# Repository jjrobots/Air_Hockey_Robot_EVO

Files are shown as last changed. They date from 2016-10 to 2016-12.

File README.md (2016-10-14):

AIR HOCKEY ROBOT EVO
====================
This is the EVOlution of the original Air Hockey Robot project!
This is version is more easy to build, user friendly, cheap and fun!

This project is an Air hockey Robot cotrolled by Arduino with a vision system to detect the puck position.
This project uses the same JJROBOTS brain shield and motors than BROBOT project and iBoardBot project

Documentation, features, how it works, build manuals and SHOP here:
URL: http://jjrobots.com/air-hockey-robot-EVO

This is the new and improved version of this old project:
URL: https://www.youtube.com/watch?v=CjzSeOg8oTs

JJROBOTS 2016. Science & fun!

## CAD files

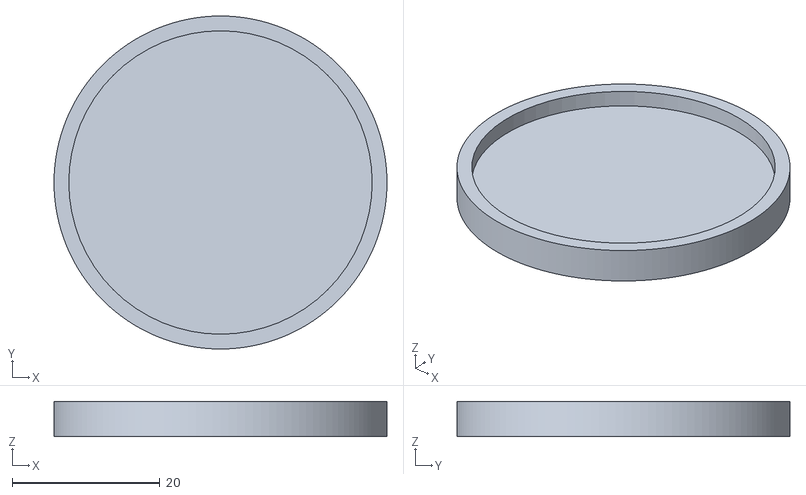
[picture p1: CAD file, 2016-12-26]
3DParts/puck.stl
45.0 x 45.0 x 4.75

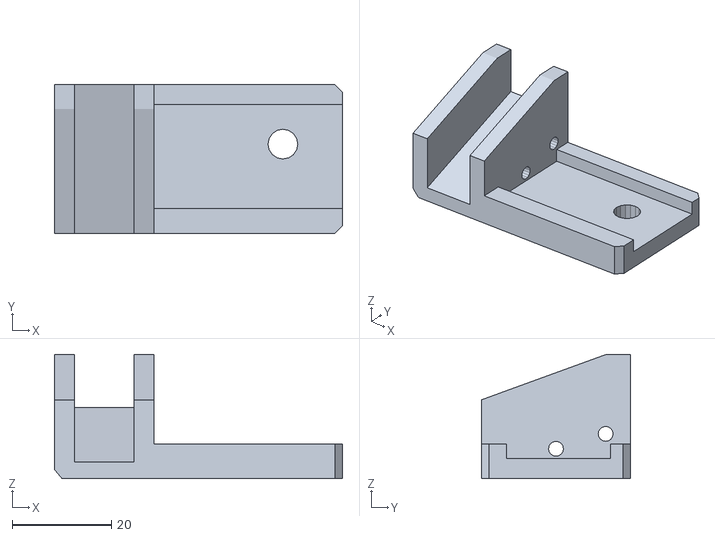
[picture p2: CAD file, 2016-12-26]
3DParts/smartphone_support.stl
58.0 x 30.0 x 25.0

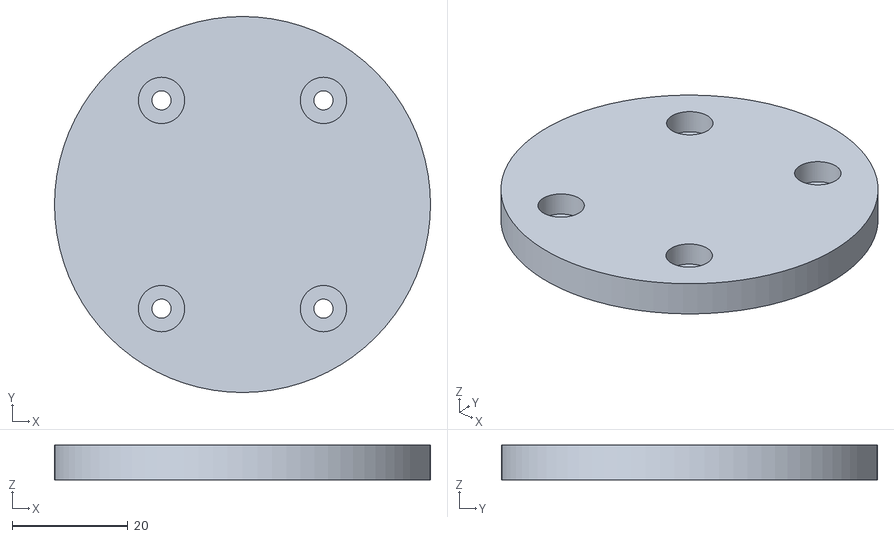
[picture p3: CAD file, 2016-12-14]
3DParts/pusher_robot2.stl
65.0 x 65.0 x 6.00

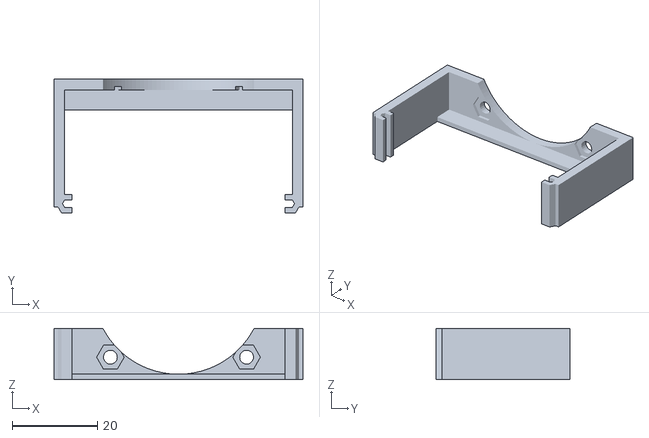
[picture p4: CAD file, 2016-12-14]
3DParts/FAN SUPPORT.stl
58.5 x 31.4 x 12.0

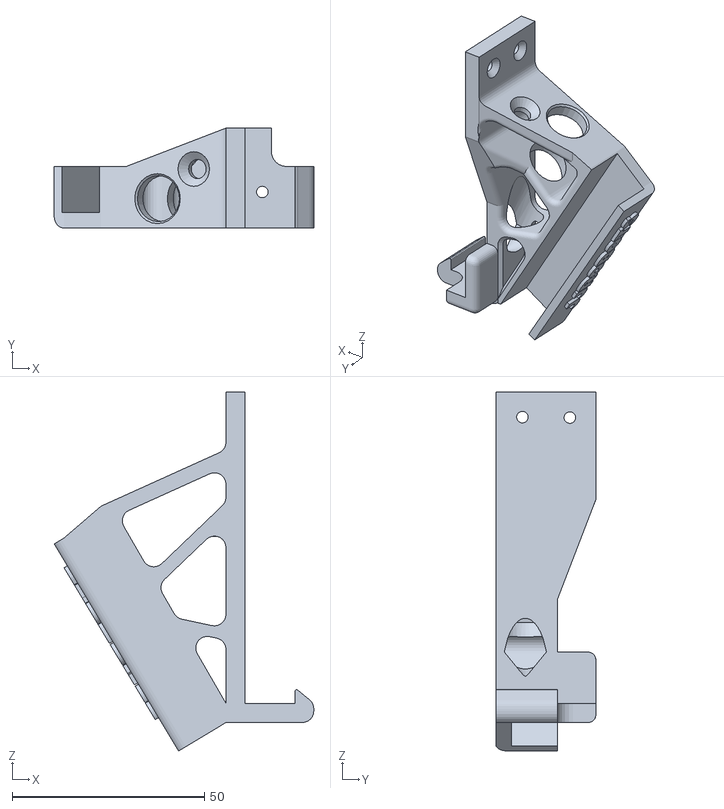
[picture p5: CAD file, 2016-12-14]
3DParts/Pole support.stl
67.6 x 26.0 x 93.4

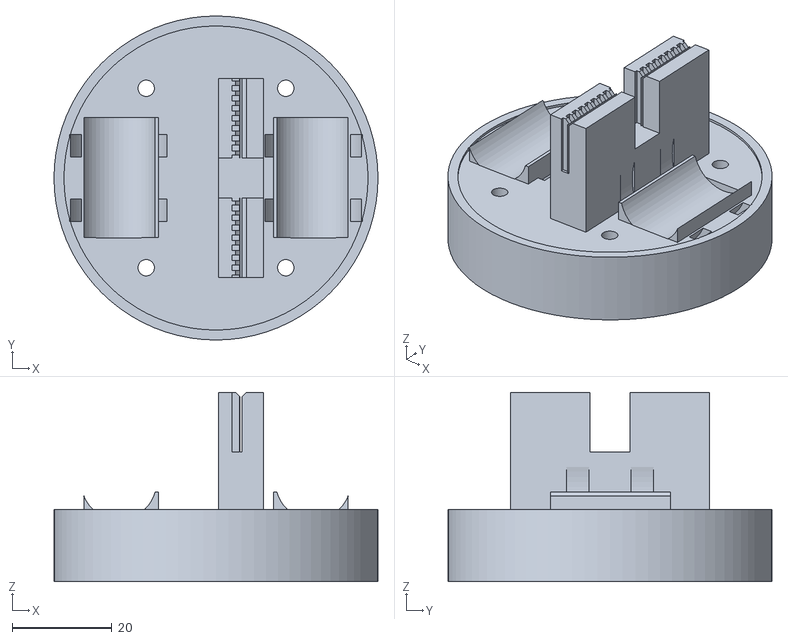
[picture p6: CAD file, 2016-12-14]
3DParts/pusher_robot.stl
65.0 x 65.0 x 38.0

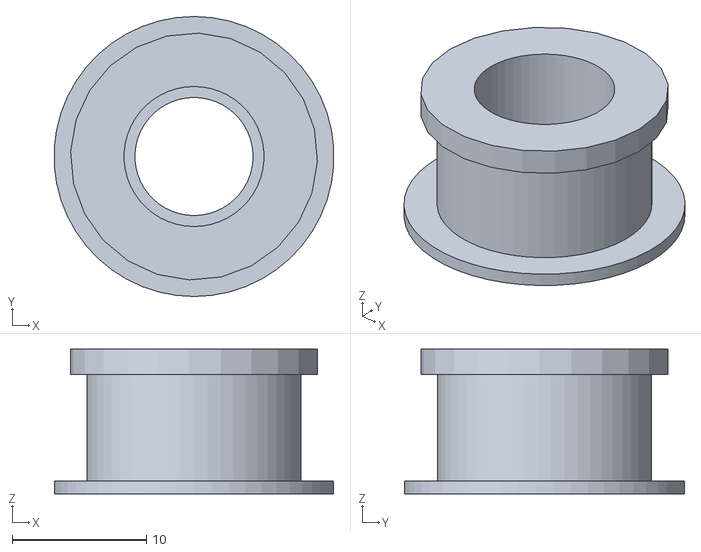
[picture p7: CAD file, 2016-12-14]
3DParts/pulley 2x623.stl
20.8 x 20.8 x 10.8

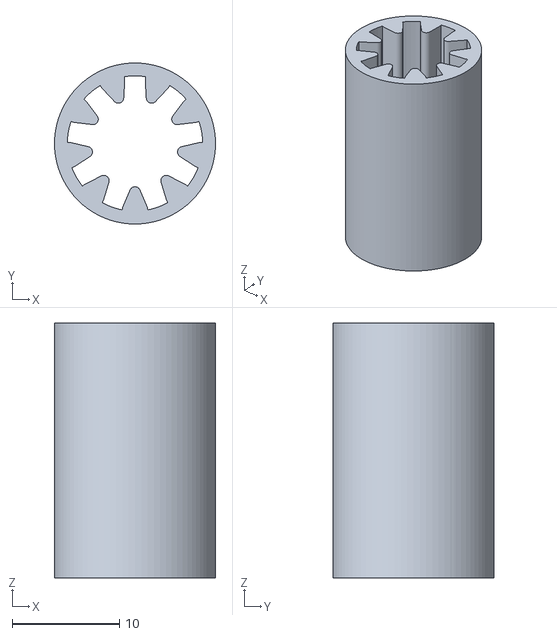
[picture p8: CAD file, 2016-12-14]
3DParts/PrintableBushing.stl
15.0 x 15.0 x 23.8

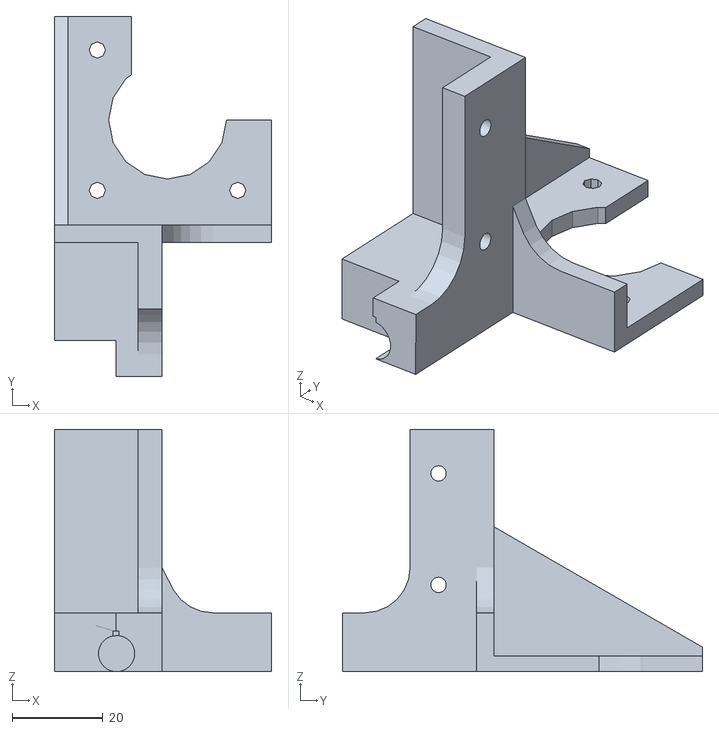
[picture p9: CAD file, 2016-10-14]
3DParts/MOTOR SUPPORT RIGHT.stl
48.0 x 79.5 x 53.5

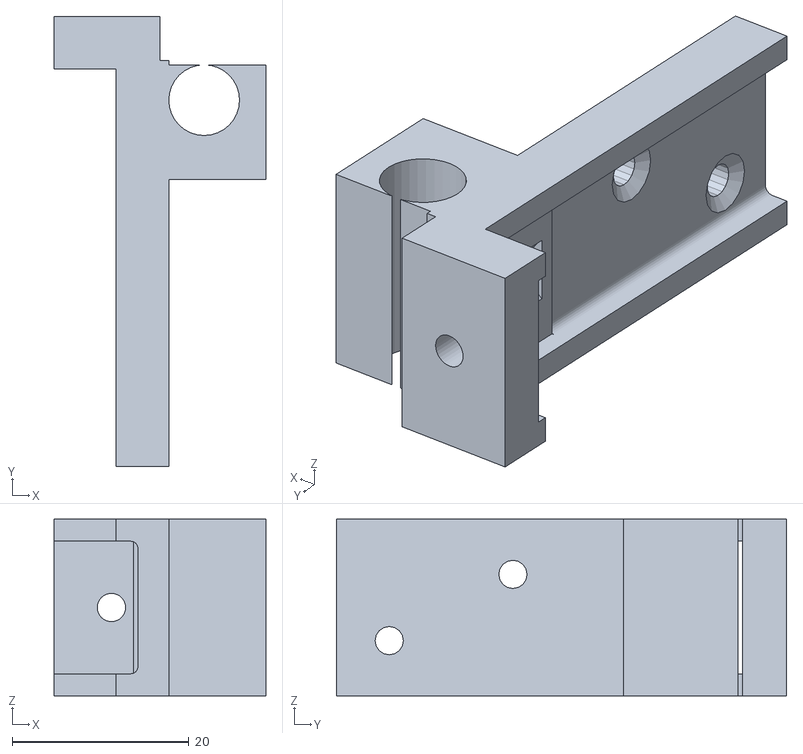
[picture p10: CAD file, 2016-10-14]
3DParts/LATERAL SUPPORT.stl
24.0 x 51.0 x 20.0

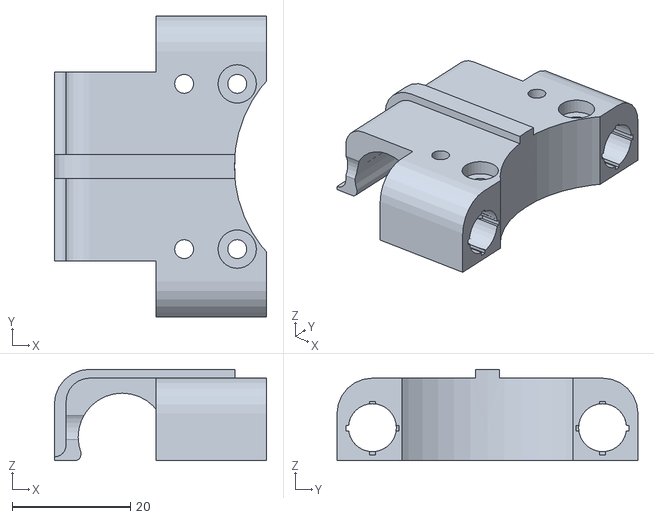
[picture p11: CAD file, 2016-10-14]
3DParts/LATERAL SLIDER.stl
36.0 x 51.0 x 15.5

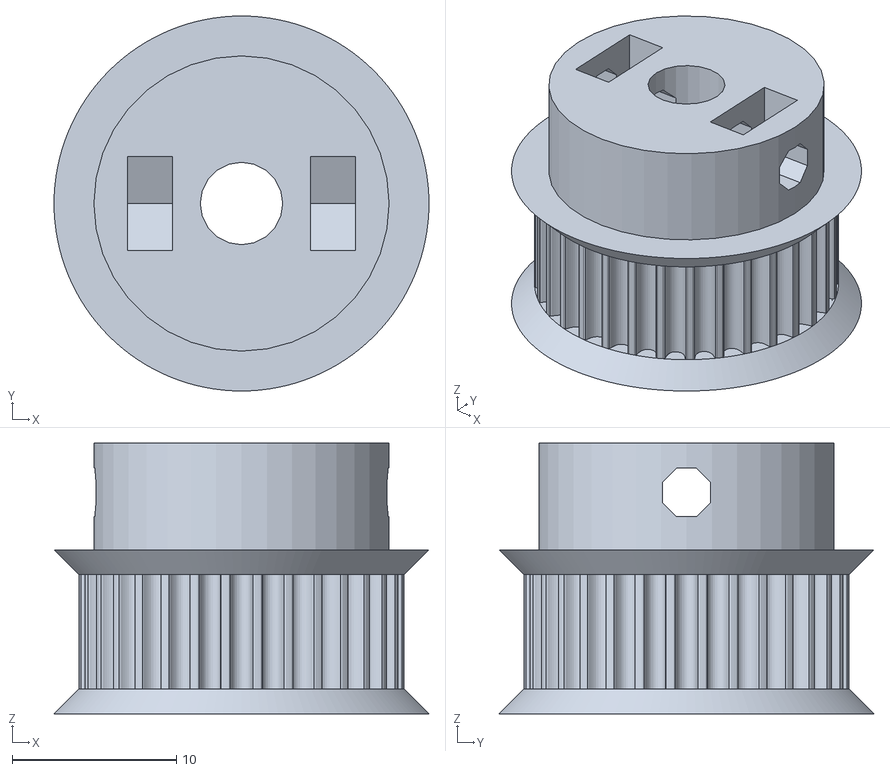
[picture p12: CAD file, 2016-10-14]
3DParts/MOTOR PULLEY.stl
22.9 x 22.9 x 16.5

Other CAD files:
3DParts/MOTOR SUPPORT LEFT.stl

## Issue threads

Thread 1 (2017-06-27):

Robot not working properly

LuisDiazUgena, 2017-06-27:
Hi!

I need to make the air hockey robot to work properly and seems that the motors are running in incorrect directions. Using the manual mode moves forward and backwards properly, but the left and right directions seems to be inverted (when need to move left it moves right and viceversa).

I have connected, from robot side, the left motor to motor1 port and the right motor to motor2 port, as said in the build instructions.

I've tested with the firmware that came preloaded and upgraded with the last code in github and I've the same problem.

Thanks!

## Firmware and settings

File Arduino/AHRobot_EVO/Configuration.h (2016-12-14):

// JJROBOTS AHR AIR HOCKEY ROBOT EVO PROJECT

// USER CONFIGURATIONS HERE
// ROBOT DIMENSIONS, MAX SPEED, MAX ACCELERATION, CALIBRATION...

//#define DEBUG

// ABSOLUTE MAX ROBOT SPEED AND ACCELERATION
// THIS VALUES DEPENDS ON YOUR ROBOT CONSTRUCTION (MOTORS, MECHANICS...)
// RECOMMENDED VALUES FOR 12V POWER SUPPLY
#define MAX_ACCEL 275           // Maximun motor acceleration in (steps/seg2)/1000. Max recommended value:280
#define MAX_SPEED 32000         // Maximun speed in steps/seg. Max absolute value: 32767!!

#define MIN_ACCEL 100
#define MIN_SPEED 5000
#define SCURVE_LOW_SPEED 2500
#define SCURVE_HIGH_SPEED 28000

// Geometric calibration.
// This depends on the pulley teeth. DEFAULT: 200(steps/rev)*8(microstepping) = 1600 steps/rev. 1600/32teeth*2mm(GT2) = 25 steps/mm
#define X_AXIS_STEPS_PER_UNIT 25    
#define Y_AXIS_STEPS_PER_UNIT 25

// This is the center of the table. All units in milimeters
// This are the dimensions of the official air hockey table Exploter from Buffalo
#define TABLE_LENGTH 895
#define TABLE_WIDTH 435
#define ROBOT_CENTER_X TABLE_WIDTH/2   // Center of robot.
#define ROBOT_CENTER_Y TABLE_LENGTH/2

// Absolute Min and Max robot positions in mm (measured from center of robot pusher)
#define ROBOT_MIN_X 60
#define ROBOT_MIN_Y 58
#define ROBOT_MAX_X TABLE_WIDTH-ROBOT_MIN_X
#define ROBOT_MAX_Y ROBOT_CENTER_Y-80

// PuckSize (puck radio in mm)
#define PUCK_SIZE 22

// Initial robot position in mm
// The robot must be at this position at start time
// Default: Centered in X and minimun position in Y
#define ROBOT_INITIAL_POSITION_X TABLE_WIDTH/2
#define ROBOT_INITIAL_POSITION_Y 40   // Measured from center of the robot pusher to the table border

// Robot defense and attack lines
#define ROBOT_DEFENSE_POSITION_DEFAULT 72
#define ROBOT_DEFENSE_ATTACK_POSITION_DEFAULT 280
#define ROBOT_DEFENSE_POSITION_MIN 60
#define ROBOT_DEFENSE_POSITION_MAX 100
#define ROBOT_DEFENSE_ATTACK_POSITION_MIN 140
#define ROBOT_DEFENSE_ATTACK_POSITION_MAX 360

// CORRECTION FOR VISION SYSTEM LAG
#define VISION_SYSTEM_LAG 60   // in miliseconds

// CORRECTION OF MISSING STEPS ON MOTORS
// Coment this lines if you don´t want to make the corrections
#define CORRECT_MISSING_STEPS 1
#define MISSING_STEPS_MAX_ERROR_X 5
#define MISSING_STEPS_MAX_ERROR_Y 5
#define ROBOT_POSITION_CAMERA_CORRECTION_Y 0 // Correction of the position of the camera because the camera point of view and mark position

// PACKET SIZE (UDP MESSAGE)
#define PACKET_SIZE 12  // UDP PACKET SIZE (without sync mark), total size = PACKET_SIZE+3(sync mark)

// Utils (don´t modify)
#define CLR(x,y) (x&=(~(1<<y)))
#define SET(x,y) (x|=(1<<y))

#define RAD2GRAD 57.2957795
#define GRAD2RAD 0.01745329251994329576923690768489

#define ZERO_SPEED 65535

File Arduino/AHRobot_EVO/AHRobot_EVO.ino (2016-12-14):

// JJROBOTS AHR: AIR HOCKEY ROBOT EVO PROJECT (Smartphone control ready!)
// Author: Jose Julio (JJROBOTS)
// Hardware: Arduino Leonardo + JJROBOTS brain shield v3 (devia)
// Date: 04/11/2015
// Last updated: 14/12/2016
// Version: 2.17
// Project page :
//   http://jjrobotos.com/air-hockey-robot-evo/
// GIT repository:
//   http://github.com/jjrobots/Air_Hockey_Robot_EVO/
// License: Open Software GPL License

#define VERSION "2.17"

// ROBOT and USER configuration parameters
#include "Configuration.h"
#include "Definitions.h"   // Variable definitions

void setup()
{
  // STEPPER PINS ON JJROBOTS BRAIN SHIELD
  pinMode(4, OUTPUT); // ENABLE MOTORS
  pinMode(7, OUTPUT); // STEP MOTOR 1 PORTE,6
  pinMode(8, OUTPUT); // DIR MOTOR 1  PORTB,4
  pinMode(12, OUTPUT); // STEP MOTOR 2 PORTD,6
  pinMode(5, OUTPUT); // DIR MOTOR 2  PORTC,6
  digitalWrite(4, HIGH);  // Disbale stepper motors

  pinMode(10, OUTPUT);  // Servo1 (arm)
  pinMode(13, OUTPUT);  // Servo2

  pinMode(A4, OUTPUT);  // Microstepping selector
  digitalWrite(A4, LOW); // 1/8 Microstepping

  pinMode(A3,INPUT);   // User puch button (pushed=>gnd)
  digitalWrite(A3,HIGH); // Enable pullup

  Serial.begin(115200);   // PC debug connection
  Serial1.begin(115200);  // ESP serial connection
  delay(5000);
  Serial.print("AHR JJRobots Air Hockey Robot EVO version ");
  Serial.println(VERSION);
  delay(1000);

  //LED blink
  for (uint8_t k = 0; k < 5; k++)
  {
    digitalWrite(13, HIGH);
    delay(300);
    digitalWrite(13, LOW);
    delay(300);
  }

  Serial.println("Initializing Wifi module...");
  // ESP Wifi module initialization routine.
  // The Robot will generate it´s own wifi network JJROBOTS_xx and listen external UDP messages...
  ESPInit();

  Serial.println("Initializing Stepper motors...");
  // STEPPER MOTORS INITIALIZATION
  // We use TIMER 1 for stepper motor 1 and Timer 3 for motor 2
  // TIMER1 CTC MODE
  TCCR1B &= ~(1 << WGM13);
  TCCR1B |=  (1 << WGM12);
  TCCR1A &= ~(1 << WGM11);
  TCCR1A &= ~(1 << WGM10);

  // output mode = 00 (disconnected)
  TCCR1A &= ~(3 << COM1A0);
  TCCR1A &= ~(3 << COM1B0);

  // Set the timer pre-scaler
  // Generally we use a divider of 8, resulting in a 2MHz timer on 16MHz CPU
  TCCR1B = (TCCR1B & ~(0x07 << CS10)) | (2 << CS10);

  OCR1A = ZERO_SPEED;   // Motor stopped
  dir_M1 = 0;
  TCNT1 = 0;

  // We use TIMER 3 for stepper motor 2
  // STEPPER MOTORS INITIALIZATION
  // TIMER3 CTC MODE
  TCCR3B &= ~(1 << WGM13);
  TCCR3B |=  (1 << WGM12);
  TCCR3A &= ~(1 << WGM11);
  TCCR3A &= ~(1 << WGM10);

  // output mode = 00 (disconnected)
  TCCR3A &= ~(3 << COM1A0);
  TCCR3A &= ~(3 << COM1B0);

  // Set the timer pre-scaler
  // Generally we use a divider of 8, resulting in a 2MHz timer on 16MHz CPU
  TCCR3B = (TCCR3B & ~(0x07 << CS10)) | (2 << CS10);

  OCR3A = ZERO_SPEED;   // Motor stopped
  dir_M2 = 0;
  TCNT3 = 0;

  delay(1000);
  TIMSK1 |= (1 << OCIE1A); // Enable Timer1 interrupt
  TIMSK3 |= (1 << OCIE1A); // Enable Timer1 interrupt

  // Enable steppers
  digitalWrite(4, LOW);

  delay(1000);

  //Initializing Robot initial position and parameters...
  position_M1 = (ROBOT_INITIAL_POSITION_X + ROBOT_INITIAL_POSITION_Y) * X_AXIS_STEPS_PER_UNIT;
  position_M2 = (ROBOT_INITIAL_POSITION_X - ROBOT_INITIAL_POSITION_Y) * Y_AXIS_STEPS_PER_UNIT;
  target_position_M1 = position_M1;
  target_position_M2 = position_M2;

  user_max_speed = MAX_SPEED;
  user_max_accel = MAX_ACCEL;
  max_acceleration = user_max_accel;
  max_speed = user_max_speed / 2;
  user_robot_defense_position = ROBOT_DEFENSE_POSITION_DEFAULT;
  user_robot_defense_attack_position = ROBOT_DEFENSE_ATTACK_POSITION_DEFAULT;
  defense_position = ROBOT_DEFENSE_POSITION_DEFAULT;   // Robot y axis defense position
  attack_position = ROBOT_DEFENSE_ATTACK_POSITION_DEFAULT;   // Robot y axis position for defense+attack

  // Output parameters to console
  Serial.print("Max_acceleration: ");
  Serial.println(user_max_accel);
  Serial.print("Max speed: ");
  Serial.println(user_max_speed);
  Serial.println("Moving to initial position...");
  Serial.println("Ready!!");

  setPosition_straight(ROBOT_CENTER_X, ROBOT_DEFENSE_POSITION_DEFAULT);

  Serial.print("Target_position:");
  Serial.print(ROBOT_CENTER_X);
  Serial.print(",");
  Serial.println(ROBOT_DEFENSE_POSITION_DEFAULT);
  //Serial.print(";");
  //Serial.print(target_position_M1);
  //Serial.print(",");
  //Serial.println(target_position_M2);

  digitalWrite(13, HIGH);
  Serial.print("AHR JJRobots Air Hockey Robot EVO version ");
  Serial.println(VERSION);
  Serial.println("ready...");

  testmode=false;
  robot_status = 0;
  timer_old = micros();
  timer_packet_old = timer_old;
  micros_old = timer_old;
}

// Main loop
void loop()
{
  int dt;
  uint8_t logOutput = 0;

  debug_counter++;

  if (analogRead(A3)<100) // pushbutton pushed => TEST PATTERN
  {
    loop_counter=0;
    testmode=true;
  }
  
  timer_value = micros();
  if ((timer_value - timer_old) >= 1000) // MAIN 1Khz loop
  {
    timer_old = timer_value;
    loop_counter++;

    packetRead();  // Check for new packets...
    if (newPacket > 0)
    {
      dt = (timer_value - timer_packet_old) / 1000.0;
      //Serial.println(dt);
      //dt = 16;  //60 Hz = 16.66ms
      timer_packet_old = timer_value;
      logOutput = 0;

      Serial.print("P");
      Serial.print(newPacket);

      if (newPacket == 1) // Camera packet
      {
        // Puck detection and trayectory prediction
        cameraProcess(dt);
        // Strategy based on puck prediction
        newDataStrategy();
        // Serial output (DEBUG)
        //Serial.print(" ");
        //Serial.print(cam_timestamp);
        //Serial.print(" ");
        //Serial.print(puckCoordX);
        //Serial.print(",");
        //Serial.print(puckCoordY);
        //Serial.print(" ");
        //Serial.print(predict_status);
        //Serial.print(",");
        //Serial.print(robot_status);
      }
      else if (newPacket == 2) { // User sends a manual move
        robot_status = 5;    // Manual mode
        Serial.print(" ");
        Serial.print(user_target_x);
        Serial.print(",");
        Serial.print(user_target_y);
      }
      else if (newPacket == 3) {
        Serial.print(" USER MAX SPEED:");
        Serial.println(user_max_speed);
        Serial.print("USER MAX ACCEL:");
        Serial.println(user_max_accel);
        Serial.print("USER DEFENSE POSITION:");
        Serial.println(user_robot_defense_position);
        Serial.print("USER ATTACK POSITION:");
        Serial.print(user_robot_defense_attack_position);
      }

      robotStrategy();

      // Robot position detection for missing steps detection in stepper motors.
      missingStepsDetection();

      Serial.println();
      newPacket = 0;
    }  // End packet received

    if (testmode)
      testMovements();

#ifdef DEBUG
    // DEBUG: We inform of the position error of the robot as seen in the camera (util for calibrations)
    if ((loop_counter % 1293) == 0) {
      Serial.print("ROBOT MSD: ");
      Serial.print(robotMissingStepsErrorX);
      Serial.print(",");
      Serial.println(robotMissingStepsErrorY);
    }
#endif

    if ((loop_counter % 10) == 0)
      updatePosition_straight();  // update straight line motion algorithm

    // Position, speed and acceleration control:
    positionControl();
  } // 1Khz loop
}

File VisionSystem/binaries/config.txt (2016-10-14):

# AHR_EVO configuration file 
CAMERA 0         # 0=FIRST CAMERA, 1=SECOND CAMERA, -1=OPEN "input.mpeg" file video
PROTOCOL UDP
CAMPIXTOMM 1.25  # THIS DEPENDS ON YOUR CAMERA POSITION
TABLELENGTH 710  # TABLE SIZE IN mm
TABLEWIDTH 400
PUCKMINH 80      # PUCK HSV DETECTION PARAMETERS
PUCKMAXH 126
PUCKMINS 35
PUCKMAXS 155
PUCKMINV 50
PUCKMAXV 190
ROBOTMINH 136      # ROBOT HSV DETECTION PARAMETERS
ROBOTMAXH 172
ROBOTMINS 126
ROBOTMAXS 217
ROBOTMINV 67
ROBOTMAXV 162
ROBOTYOFFSET 38  # Robot offset from robot mark (projected to table) to robot puck center
FPS 60
VIDEOOUTPUT YES  # YES or NO
LOG YES          # YES or NO
PREVIEW YES      # YES or NO or RAW

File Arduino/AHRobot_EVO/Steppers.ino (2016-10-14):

// JJROBOTS AHR AIR HOCKEY ROBOT EVO PROJECT
// STEPPERS MOTOR CONTROL
// Updated: Now it supports DRV8825 drivers and A4988 drivers
// SPEED, ACCELERATION AND POSITION CONTROL using Arduino 16 bit Timer interrupts
// We control the speed of the motors with interrupts (Timer1 and Timer3). tested up to 32Khz.
// The position of the motor is controlled at 1Khz (in the main loop)

// TIMER 1 : STEPPER MOTOR SPEED CONTROL MOTOR1
ISR(TIMER1_COMPA_vect)
{
  if (dir_M1 == 0)
    return;

  SET(PORTE, 6); // STEP X-AXIS (MOTOR1)
  position_M1 += dir_M1;
  __asm__ __volatile__ (
    "nop" "\n\t"
    "nop" "\n\t"
    "nop" "\n\t"
    "nop" "\n\t"
    "nop" "\n\t"
    "nop" "\n\t"
    "nop" "\n\t"
    "nop" "\n\t"
    "nop" "\n\t"
    "nop" "\n\t"
    "nop" "\n\t"
    "nop");  // Wait for step pulse
  CLR(PORTE, 6);
}

// TIMER 3 : STEPPER MOTOR SPEED CONTROL MOTOR2
ISR(TIMER3_COMPA_vect)
{
  if (dir_M2 == 0)
    return;

  SET(PORTD, 6); // STEP Y-AXIS (Motor2)
  position_M2 += dir_M2;
  __asm__ __volatile__ (
    "nop" "\n\t"
    "nop" "\n\t"
    "nop" "\n\t"
    "nop" "\n\t"
    "nop" "\n\t"
    "nop" "\n\t"
    "nop" "\n\t"
    "nop" "\n\t"
    "nop" "\n\t"
    "nop");  // Wait for step pulse
  CLR(PORTD, 6);
}

// POSITION CONTROL
// We use a ramp for acceleration and deceleration
// To calculate the point we should start to decelerate we use this formula:
// stop_position = actual_posicion + (actual_speed*actual_speed)/(2*max_deceleration)
// Input parameters:
//    target_position_M1
//    target_speed_M1
//    max_acceleration

void positionControl()
{
  int32_t temp;
  uint32_t timer;
  int16_t dt;
  int16_t result_speed_M1, result_speed_M2;
  int16_t absSpeedM1, absSpeedM2;


  real_position_x = ((position_M1 + position_M2) / 2) / X_AXIS_STEPS_PER_UNIT;
  real_position_y = ((position_M1 - position_M2) / 2) / Y_AXIS_STEPS_PER_UNIT;
  //SET(PORTF,3); // for external timing debug
  timer = micros();
  // dt = delta time in microseconds...
  dt = constrain(timer - micros_old, 0, 2000); // Limit dt (it should be around 1000 most times, 1ms)
  //Serial.println(dt);
  micros_old = timer;

  // Movement accelerations...
  acceleration_M1 = max_acceleration;
  acceleration_M2 = max_acceleration;

  // Scurve profile implementation...
  absSpeedM1 = abs(speed_M1);
  absSpeedM2 = abs(speed_M2);
  if (absSpeedM1 < SCURVE_LOW_SPEED) {
    acceleration_M1 = map(absSpeedM1, 0, SCURVE_LOW_SPEED, MIN_ACCEL, max_acceleration);
    if (acceleration_M1 > max_acceleration)
      acceleration_M1 = max_acceleration;
  }
  if (absSpeedM2 < SCURVE_LOW_SPEED) {
    acceleration_M2 = map(absSpeedM2, 0, SCURVE_LOW_SPEED, MIN_ACCEL, max_acceleration);
    if (acceleration_M2 > max_acceleration)
      acceleration_M2 = max_acceleration;
  }
  // SCURVE FACOR 1900!!!

  // MOTOR1 M1
  temp = (long)speed_M1 * speed_M1;
  temp = temp / (1900 * (long)acceleration_M1);
  pos_stop_M1 = position_M1 + sign(speed_M1) * temp;    // We calculate the stop position if we apply a deceleration right now.
  if (target_position_M1 > position_M1)    // Positive move
  {
    if (pos_stop_M1 >= target_position_M1)  // Do we need to start stopping?
      result_speed_M1 = 0;                    // The deceleration ramp is done inside the setSpeed function
    else
      result_speed_M1 = target_speed_M1;      // The aceleration ramp is done inside the setSpeed function
  }
  else   // Negative move
  {
    if (pos_stop_M1 <= target_position_M1)  // Start decelerating?
      result_speed_M1 = 0;
    else
      result_speed_M1 = -target_speed_M1;
  }

  // MOTOR2 M2
  temp = (long)speed_M2 * speed_M2;
  temp = temp / (1900 * (long)acceleration_M2);
  pos_stop_M2 = position_M2 + sign(speed_M2) * temp;
  if (target_position_M2 > position_M2) // Positive move
  {
    if (pos_stop_M2 >= target_position_M2)  // Start decelerating?
      result_speed_M2 = 0;                  // The deceleration ramp is done inside the setSpeed function
    else
      result_speed_M2 = target_speed_M2;    // The aceleration ramp is done inside the setSpeed function
  }
  else   // Negative move
  {
    if (pos_stop_M2 <= target_position_M2)  // Start decelerating?
      result_speed_M2 = 0;
    else
      result_speed_M2 = -target_speed_M2;
  }

  setMotorSpeed(result_speed_M1, result_speed_M2, dt); // change Motors speed
  //CLR(PORTF,3); // for external timing debug
}

// Speed could be positive or negative
void setMotorSpeed(int16_t m1tspeed, int16_t m2tspeed, int16_t dt)
{
  long timer_period;
  int16_t accel;

  // Limit max speeds
  m1tspeed = constrain(m1tspeed, -user_max_speed, user_max_speed);
  m2tspeed = constrain(m2tspeed, -user_max_speed, user_max_speed);

  // M1 MOTOR
  // We limit acceleration => speed ramp
  accel = ((long)acceleration_M1 * dt) / 1000; // We divide by 1000 because dt are in microseconds
  if (((long)m1tspeed - speed_M1) > accel) // We use long here to avoid overflow on the operation
    speed_M1 += accel;
  else if (((long)speed_M1 - m1tspeed) > accel)
    speed_M1 -= accel;
  else
    speed_M1 = m1tspeed;

  // Check if we need to change the direction pins
  if ((speed_M1 == 0) && (dir_M1 != 0))
    dir_M1 = 0;
  else if ((speed_M1 > 0) && (dir_M1 != 1))
  {
    CLR(PORTB, 4);
    dir_M1 = 1;
  }
  else if ((speed_M1 < 0) && (dir_M1 != -1))
  {
    SET(PORTB, 4);
    dir_M1 = -1;
  }

  if (speed_M1 == 0)
    timer_period = ZERO_SPEED;
  else if (speed_M1 > 0)
    timer_period = 2000000 / speed_M1; // 2Mhz timer
  else
    timer_period = 2000000 / -speed_M1;

  if (timer_period > 65535)   // Check for minimun speed (maximun period without overflow)
    timer_period = ZERO_SPEED;

  OCR1A = timer_period;
  // Check  if we need to reset the timer...
  if (TCNT1 > OCR1A)
    TCNT1 = 0;

  // M2 MOTOR
  // We limit acceleration => speed ramp
  accel = ((long)acceleration_M2 * dt) / 1000;
  if (((long)m2tspeed - speed_M2) > accel)
    speed_M2 += accel;
  else if (((long)speed_M2 - m2tspeed) > accel)
    speed_M2 -= accel;
  else
    speed_M2 = m2tspeed;

  // Check if we need to change the direction pins
  if ((speed_M2 == 0) && (dir_M2 != 0))
    dir_M2 = 0;
  else if ((speed_M2 > 0) && (dir_M2 != 1))
  {
    CLR(PORTC, 6);
    dir_M2 = 1;
  }
  else if ((speed_M2 < 0) && (dir_M2 != -1))
  {
    SET(PORTC, 6);
    dir_M2 = -1;
  }

  if (speed_M2 == 0)
    timer_period = ZERO_SPEED;
  else if (speed_M2 > 0)
    timer_period = 2000000 / speed_M2; // 2Mhz timer
  else
    timer_period = 2000000 / -speed_M2;

  if (timer_period > 65535)   // Check for minimun speed (maximun period without overflow)
    timer_period = ZERO_SPEED;

  OCR3A = timer_period;
  // Check  if we need to reset the timer...
  if (TCNT3 > OCR3A)
    TCNT3 = 0;

}
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

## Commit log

2016-10-14 Air Hockey Robot EVO
    First commit of new Air Hockey Robot EVO project!
    A fun robot project from JJrobots
    [623 PULLEY.stl, CAMERA SUPPORT BASE.stl, CAMERA SUPPORT TOP.stl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]
2016-10-19 Added new 3D part
    [Cable Support.stl]
2016-12-14 Update to new 3d parts
    new 3d parts for the new table
    [623 PULLEY.stl, CAMERA SUPPORT BASE.stl, CAMERA SUPPORT TOP.stl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]
2016-12-14 New version of arduino code
    smartphone prepared code...
    [Configuration.h]
2016-12-26 new 3D parts
    New 3D parts, puck (you need to use support material) and a new
    smartphone support part
    [puck.stl, pusher_robot.stl, pusher_robot2.stl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]
